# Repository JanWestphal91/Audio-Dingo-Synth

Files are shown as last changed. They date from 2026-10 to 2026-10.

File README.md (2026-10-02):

<h1 align="center">AudioDingo</h1>

<p align="center">
  A pocket-sized, battery-powered synthesizer built on the Arduino UNO R4 Minima and the Mozzi audio library.
</p>

<p align="center">
  
  
  
</p>

<p align="center">
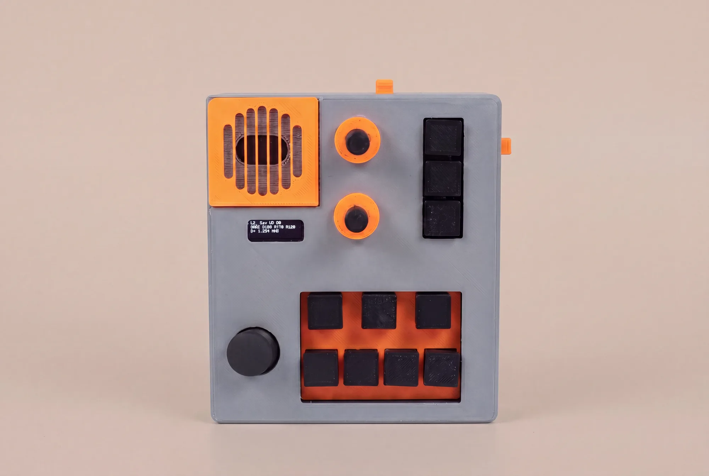
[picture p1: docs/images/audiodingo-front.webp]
AudioDingo front view
  
</p>

AudioDingo is a standalone mini synth with seven note keys, three function buttons, two rotary encoders, a joystick and a small OLED display. It has a built-in speaker for playing on its own and a headphone/line jack for connecting to a larger synth setup. Everything sits in a custom 3D-printed enclosure designed in Fusion 360.

The full design process is documented on my blog: **[Development process of a DIY synthesizer](https://janwestphal.dev/blog/hello-blog/)**

## Demo

<p align="center">
  <a href="https://www.youtube.com/watch?v=iitkykF2S_k">
    AudioDingo demo video on YouTube
  </a>
  <br>
  <em>▶ Watch the demo on YouTube</em>
</p>

## Features

- **6 waveforms:** saw, pulse, triangle, sine, 2-operator FM and noise
- **Chord mode:** each key plays three voices (major, minor, sus4, octaves)
- **5 presets:** lead, bass, FM bell, sub and a sine kick drum
- **"Happy Accident" button:** generates a random patch
- **Resonant low-pass filter** with its own envelope
- **ADSR envelope** you can edit live with an encoder
- **Pitch envelope, LFO, bit crusher and noise layer**, defined per preset
- **Joystick performance controls:** vibrato, wah filter, bit crush and glide
- **128×32 OLED** status screen, plus an animated visualizer mode
- **Portable:** runs on a battery, with a built-in speaker and a headphone/line output

## Design process

The project went from a list of requirements through a simulation, breadboard prototypes and two enclosure iterations to the finished device.

1. **Requirements.** Seven note keys, because a scale has seven notes. Three function buttons and two encoders to shape the sound. A display for feedback. A speaker for standalone use, a jack for the rest of the setup, and a battery for portability.
2. **Simulation.** I tested a first version of the circuit on [Wokwi](https://wokwi.com/).
3. **Breadboard prototype.** I researched which components work together, then built and tested them on a breadboard.
4. **Enclosure v1.** I designed a case in Fusion 360 and printed only the main body, to check the layout with all parts installed.
5. **Iteration.** I soldered the electronics, moved the sound engine to Mozzi and redesigned the case to be wider and deeper, with revised button, cutout and connector dimensions. The second print fit.

<table>
  <tr>
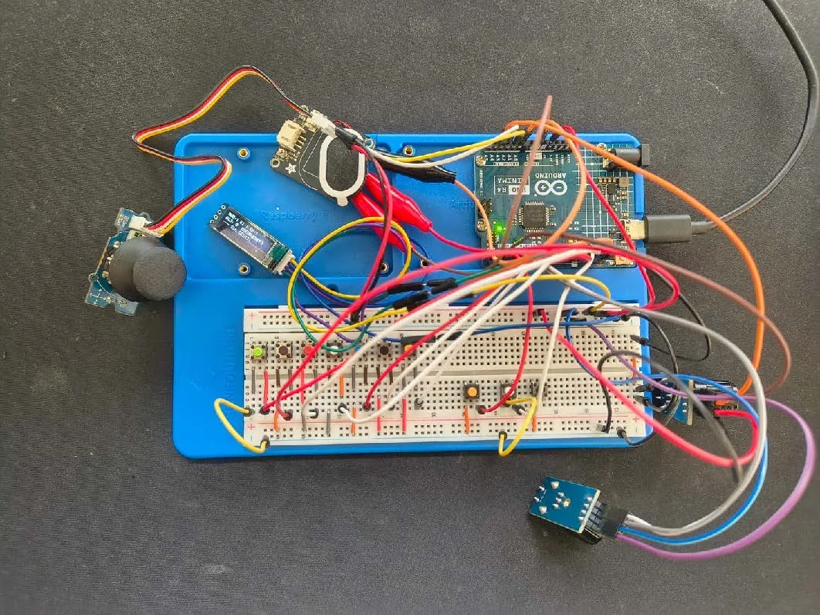
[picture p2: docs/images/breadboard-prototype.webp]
Breadboard prototype
    <td align="center" width="33%"><br><sub>Breadboard prototype</sub></td>
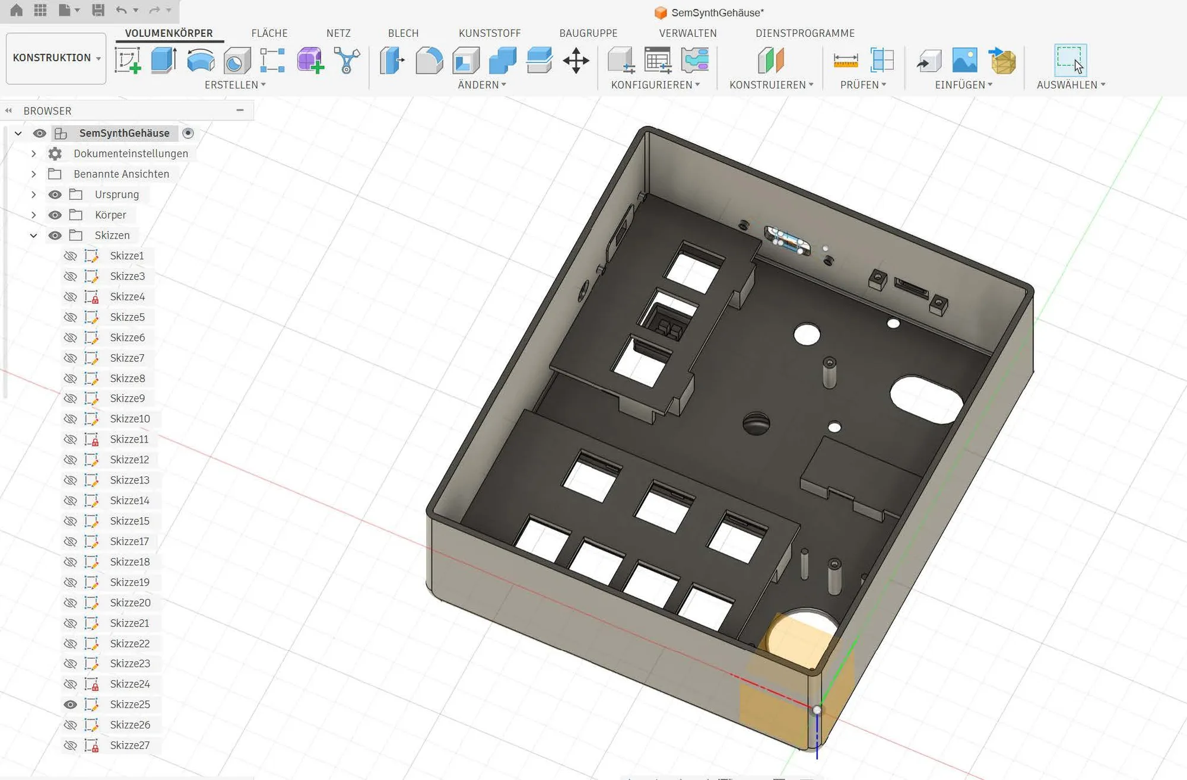
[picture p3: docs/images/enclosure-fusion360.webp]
Enclosure design in Fusion 360
    <td align="center" width="33%"><br><sub>Enclosure design in Fusion 360</sub></td>
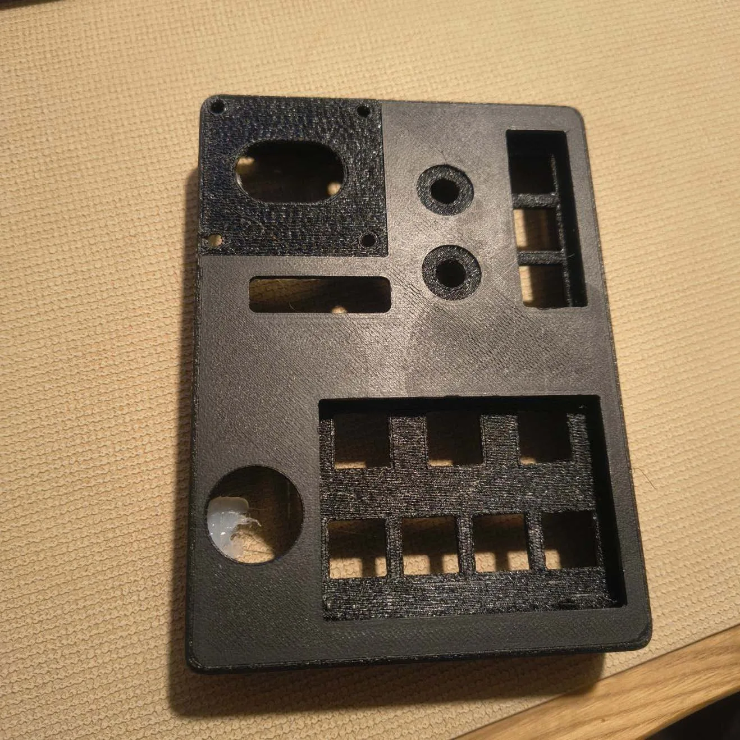
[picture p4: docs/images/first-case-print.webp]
First printed case
    <td align="center" width="33%"><br><sub>First test print of the case</sub></td>
  </tr>
</table>

## Hardware

<p align="center">
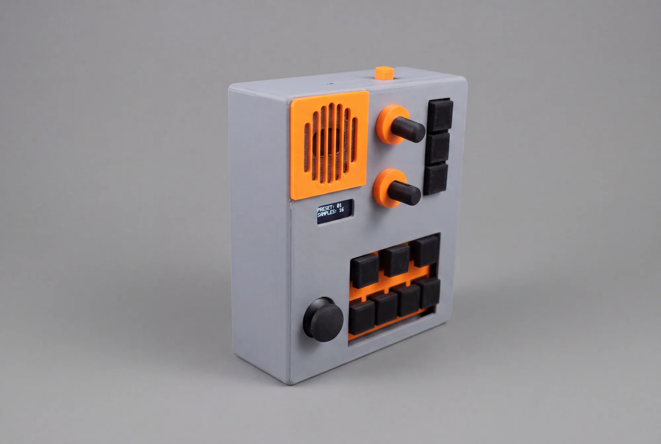
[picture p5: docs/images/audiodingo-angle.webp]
AudioDingo angled view
  
</p>

| Part | Notes |
|---|---|
| Arduino UNO R4 Minima | Outputs audio through its on-board 12-bit DAC on pin A0 |
| 7 push buttons | note keys |
| 3 push buttons | MODE, WAVE, CHORD |
| 2 rotary encoders | quadrature encoders with detents |
| Analog thumb joystick | 2 axes (X/Y) |
| SSD1306 OLED, 128×32, I²C | address `0x3C` |
| Small class-D amplifier + speaker | fed from A0 |
| Headphone / line jack | connects to other synths |
| Battery pack | for portable use |
| 3D-printed enclosure | see [`hardware/enclosure`](hardware/enclosure) |

All buttons connect between the pin and **GND**. The firmware enables the internal pull-up resistors, so you don't need external resistors.

### Pinout

| Pin | Function |
|---|---|
| D12, D11, D10, D9, D8, D7, D6 | Note keys C4 D4 E4 F4 G4 A4 B4 (low to high) |
| D3 | MODE button |
| A4 | WAVE button |
| A5 | CHORD button |
| D4, D5 | Encoder 1 (A, B) |
| D2, A3 | Encoder 2 (A, B) |
| A1, A2 | Joystick X, Y |
| A0 | Audio out (DAC) → amplifier |
| SDA, SCL | OLED display |

You can change every pin in [`firmware/AudioDingo/config.h`](firmware/AudioDingo/config.h).

### Hardware notes

- **Audio output:** On the UNO R4, Mozzi always plays audio through the internal DAC on **A0**. You can't move it to another pin. The firmware also defines A0 as `AMP_ENABLE_PIN`, but once Mozzi is running, the DAC controls the pin.
- **I²C pins:** On the UNO R4 Minima, **A4/A5 are the same pins as SDA/SCL**. In this build, the WAVE and CHORD buttons share these lines with the display. If you build your own, move these two buttons to free pins, e.g. D13 or D0/D1.

## Controls

| Control | Action |
|---|---|
| Note keys | Play a note (or a chord in chord mode) |
| Encoder 1 | Change the selected envelope value (A / D / S / R) |
| Encoder 1 + hold MODE | Select which envelope value to edit |
| Encoder 2 | Volume (1–15) |
| Encoder 2 + hold MODE | Select preset |
| Encoder 2 + hold CHORD | Octave shift −3…+3 (in chord mode) |
| MODE (tap) | Chord mode on/off |
| CHORD (tap) | Next chord type (chord mode) / random patch (otherwise) |
| WAVE (tap) | Next waveform |
| WAVE (hold 0.4 s) | Toggle visualizer screen |
| Joystick ↑ | Vibrato |
| Joystick ↓ | Close filter (wah) |
| Joystick → | Bit crush |
| Joystick ← | Glide / portamento |

### Display

```
Ld  Saw V8 O0          preset, waveform, volume, octave
[A5] D180 S170 R120    envelope; the value being edited is in [brackets]
Dt 1.004 RND           detune, "Crsh" when bit crush is on, chord type (RND = random-patch mode)
```

## How the sound engine works

Every note runs through this chain:

```
 oscillators ──► + noise ──► low-pass filter ──► × envelope ──► × volume ──► bit crush ──► DAC
 (1 or 3 voices)              ▲                    ▲
                              │                    │
             cutoff + filter envelope        amplitude ADSR
             + LFO + joystick
```

- **Oscillators:** Each voice has two oscillators. For saw, pulse and triangle, the second one is slightly detuned and the output is the difference of the two. As the oscillators drift in and out of phase, the waveform keeps changing. For FM, the second oscillator modulates the phase of the first, which produces bell-like and metallic sounds.
- **Control rate and audio rate:** Mozzi calls `updateControl()` 128 times per second to handle inputs, envelopes, pitch and the display. It calls `updateAudio()` 32,768 times per second, and each call computes one sample. The code comments explain why slow work belongs in the first function and only fast math in the second.
- **Click-free display:** An I²C transfer to the OLED briefly pauses audio generation. To avoid clicks, the status screen only redraws when a displayed value has changed.

## Building the firmware

1. Install the **Arduino IDE** (2.x) or `arduino-cli`.
2. Install the board package **Arduino UNO R4 Boards** (`arduino:renesas_uno`).
3. Install these libraries with the Library Manager. The versions listed are the ones I tested:

   | Library | Version |
   |---|---|
   | Mozzi | 2.0.4 |
   | Adafruit SSD1306 | 2.5.17 |
   | Adafruit GFX Library | 1.12.6 |
   | Adafruit BusIO | 1.17.4 (dependency) |
   | FixMath | 1.0.9 (Mozzi dependency) |

4. Open `firmware/AudioDingo/AudioDingo.ino`, select **Arduino UNO R4 Minima** and upload.

With `arduino-cli`:

```bash
arduino-cli compile --fqbn arduino:renesas_uno:minima firmware/AudioDingo
arduino-cli upload  --fqbn arduino:renesas_uno:minima -p <PORT> firmware/AudioDingo
```

## Customizing

| What | Where |
|---|---|
| Pins | `firmware/AudioDingo/config.h` |
| Scale of the note keys | `NOTE_MIDI_NUMBERS` in `config.h` |
| Sounds | `PRESETS[]` and `PRESET_NAMES[]` in `presets.h` (each field is documented in the `Preset` struct) |
| Chords | `CHORD_INTERVALS` in `presets.h` |

## Repository structure

```
├── firmware/AudioDingo/
│   ├── AudioDingo.ino   main program: sound engine, inputs, display, Mozzi callbacks
│   ├── config.h         pins and hardware constants
│   ├── presets.h        waveforms, presets and chord definitions
│   └── encoder.h        debounced rotary encoder decoder
├── hardware/enclosure/  3D-printable enclosure files
└── docs/images/         photos for this README
```

## Credits

- [Mozzi](https://github.com/sensorium/Mozzi) by Tim Barrass and contributors (LGPL-2.1)
- [Adafruit SSD1306](https://github.com/adafruit/Adafruit_SSD1306) and [Adafruit GFX](https://github.com/adafruit/Adafruit-GFX-Library) (BSD)

These libraries are not part of this repository. You install them separately, and their own licenses apply.

## License

[MIT](LICENSE) © 2026 Jan Westphal: firmware, enclosure files and documentation.

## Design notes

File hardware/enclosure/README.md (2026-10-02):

# Enclosure

3D-printable enclosure for AudioDingo, designed in Fusion 360.

<p align="center">
  Enclosure in Fusion 360
</p>

The case is printed in several colors: a grey main body, orange accents and black caps.

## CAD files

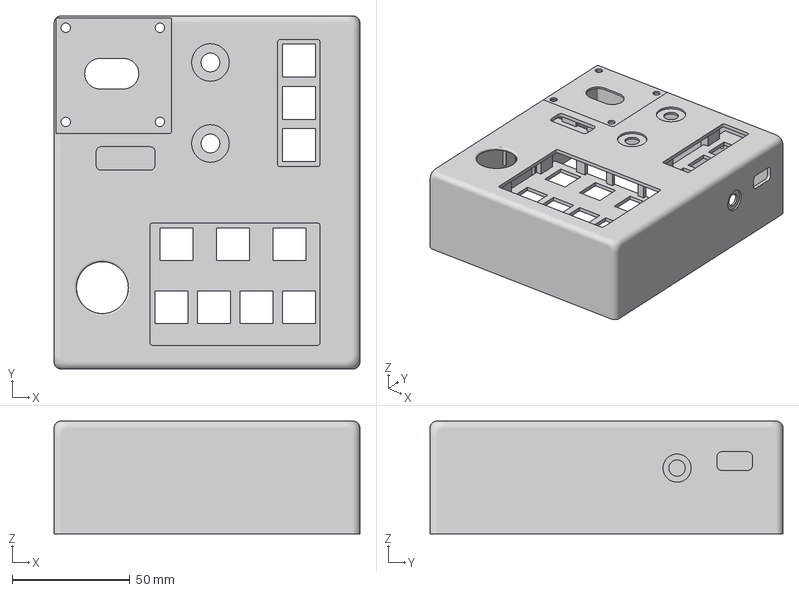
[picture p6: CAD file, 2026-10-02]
hardware/enclosure/DingoCase.3mf
130.0 x 150.0 x 48.0 mm

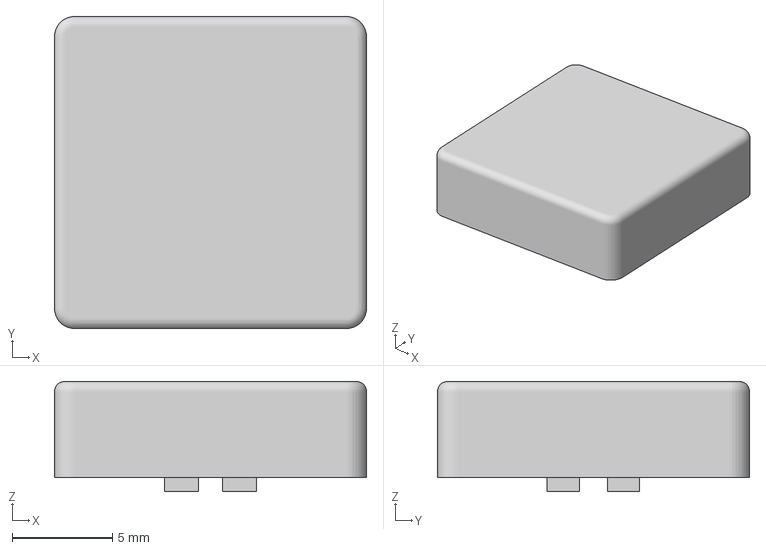
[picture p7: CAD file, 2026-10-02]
hardware/enclosure/Button_small.3mf
15.6 x 15.6 x 5.50 mm

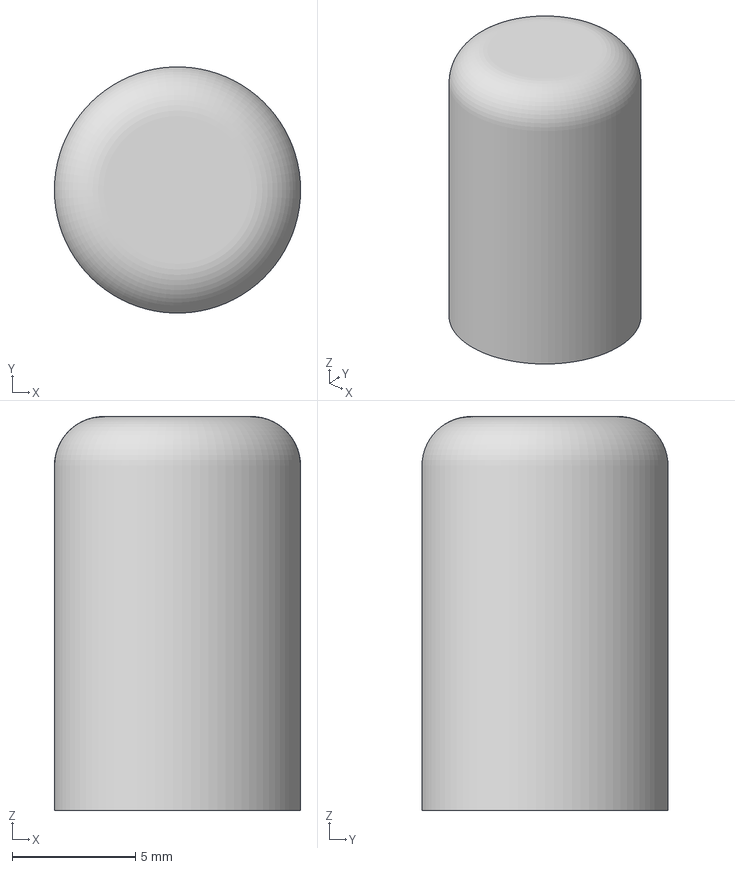
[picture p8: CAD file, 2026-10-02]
hardware/enclosure/Poti_cap.3mf
10.00 x 9.99 x 16.0 mm

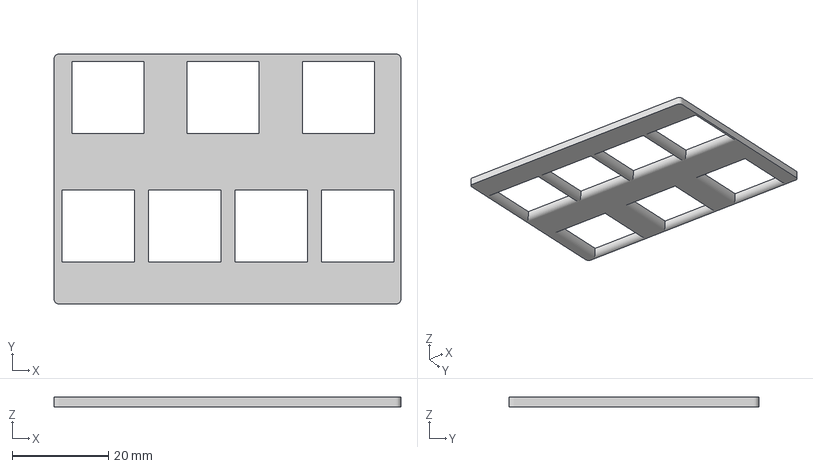
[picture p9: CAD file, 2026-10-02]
hardware/enclosure/Button_Shield.3mf
72.2 x 52.0 x 2.00 mm

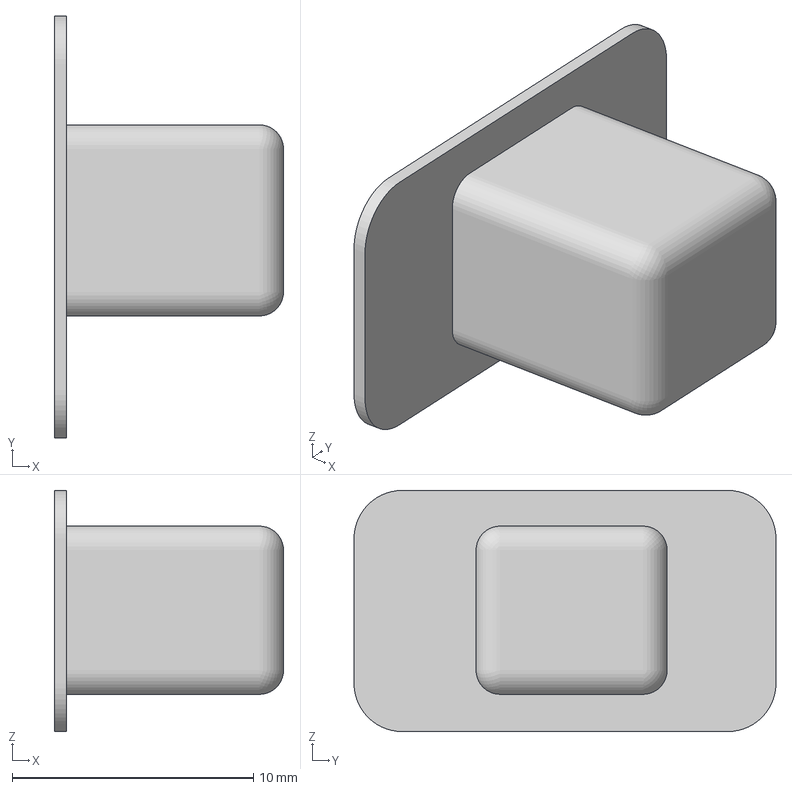
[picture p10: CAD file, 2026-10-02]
hardware/enclosure/Switch_cap.3mf
9.50 x 17.5 x 10.0 mm

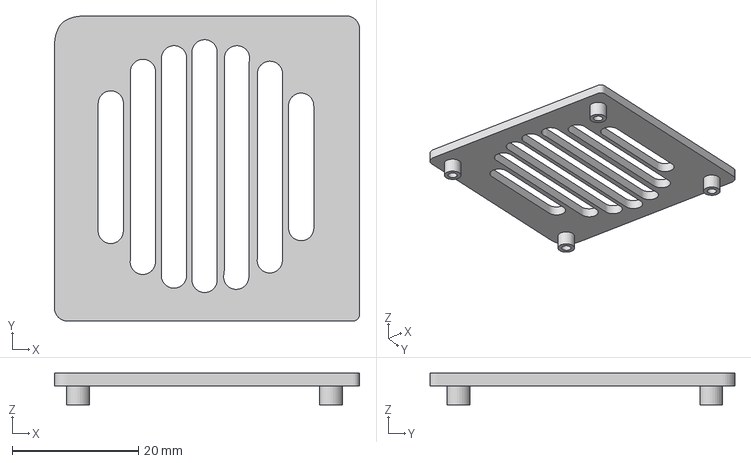
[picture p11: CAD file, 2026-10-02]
hardware/enclosure/speaker_shield.3mf
48.2 x 48.2 x 5.00 mm

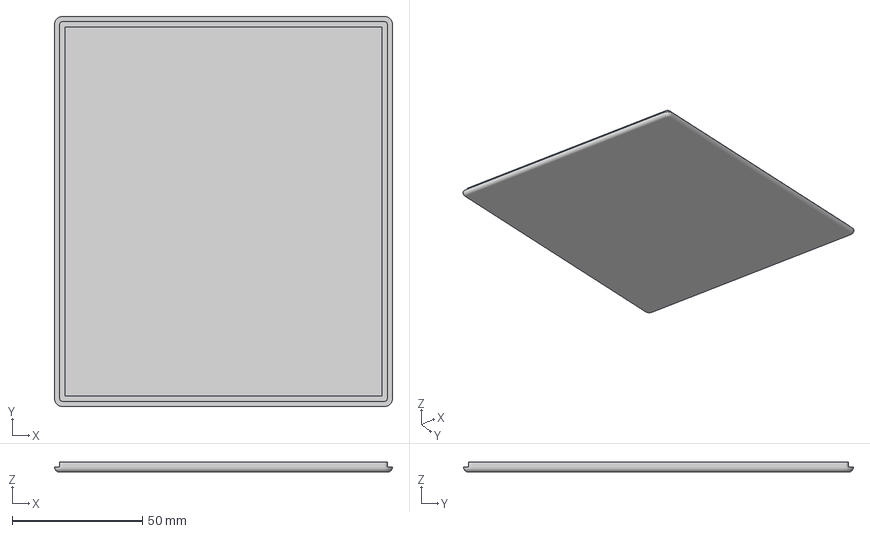
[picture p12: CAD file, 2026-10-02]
hardware/enclosure/Dingo_case2.3mf
130.0 x 150.0 x 4.00 mm

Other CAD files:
hardware/enclosure/poty_ring.3mf

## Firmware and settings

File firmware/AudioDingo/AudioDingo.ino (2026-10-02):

// =============================================================================
//  AudioDingo — a pocket synthesizer for the Arduino UNO R4 Minima
// =============================================================================
//
//  Copyright (c) 2026 Jan Westphal — MIT License (see LICENSE)
//  Project write-up: https://janwestphal.dev/blog/hello-blog/
//
//  A small, battery-powered, 3-voice synthesizer built on the Mozzi audio
//  library. Each preset defines its own waveform, FM, noise, pitch envelope,
//  bit crush and LFO, so the few controls can produce very different sounds —
//  from leads and basses to bells and drum hits.
//
//  ---------------------------------------------------------------------------
//  Controls
//  ---------------------------------------------------------------------------
//   7 note keys          play a note (or a 3-note chord in chord mode)
//
//   Encoder 1            change the selected envelope value (A, D, S or R)
//     + hold MODE        select which envelope value to edit
//
//   Encoder 2            master volume (1..15)
//     + hold MODE        select preset
//     + hold CHORD       octave shift (only in chord mode)
//
//   MODE   (tap)         chord mode on/off
//   CHORD  (tap)         chord mode: next chord type / otherwise: random patch
//   WAVE   (tap)         next waveform
//   WAVE   (hold 0.4 s)  toggle the animated "visualizer" screen
//
//   Joystick up          vibrato
//   Joystick down        close the filter (wah)
//   Joystick right       bit crush
//   Joystick left        glide / portamento between notes
//
//  ---------------------------------------------------------------------------
//  How Mozzi structures the program
//  ---------------------------------------------------------------------------
//  Mozzi splits the work into two callbacks with different speeds:
//
//   updateControl()  runs MOZZI_CONTROL_RATE times per second (here 128 Hz).
//                    Reads buttons, encoders, joystick; updates envelopes,
//                    pitch, filter and the display. Can be relatively slow.
//
//   updateAudio()    runs MOZZI_AUDIO_RATE times per second (32768 Hz on the
//                    R4). Computes ONE audio sample. Must be very fast — no
//                    analogRead(), no display, no floating-point heavy work.
//
//  loop() only calls audioHook(), which keeps Mozzi's audio buffer filled and
//  calls the two functions above when needed. Never use delay() in a Mozzi sketch.
// =============================================================================

// Must be defined BEFORE including Mozzi.h.
#define MOZZI_CONTROL_RATE 128

#include <Mozzi.h>
#include <Phasor.h>
#include <ADSR.h>
#include <LowPassFilter.h>
#include <mozzi_midi.h>

#include <Wire.h>
#include <Adafruit_GFX.h>
#include <Adafruit_SSD1306.h>

#include "config.h"
#include "presets.h"
#include "encoder.h"

// =============================================================================
//  Global objects
// =============================================================================

Adafruit_SSD1306 display(SCREEN_WIDTH, SCREEN_HEIGHT, &Wire, OLED_RESET_PIN);

// Three voices with two oscillators each.
// A Phasor is a simple counter that wraps around once per period. Its 32-bit
// output is the "phase" (position within one waveform cycle), which the wave
// shaper functions below turn into an actual waveform.
//   osc?a = main oscillator (carrier)
//   osc?b = detuned partner OR FM modulator, depending on the waveform
// Voice 1 always plays; voices 2 and 3 are only used in chord mode.
Phasor<MOZZI_AUDIO_RATE> osc1a, osc1b;
Phasor<MOZZI_AUDIO_RATE> osc2a, osc2b;
Phasor<MOZZI_AUDIO_RATE> osc3a, osc3b;

// Two envelopes: one shapes the volume of each note, the other opens and
// closes the filter over the course of a note.
ADSR<MOZZI_CONTROL_RATE, MOZZI_AUDIO_RATE> ampEnvelope;
ADSR<MOZZI_CONTROL_RATE, MOZZI_AUDIO_RATE> filterEnvelope;

// Resonant low-pass filter applied to the mixed voices.
LowPassFilter lowPass;

// Rotary encoders. The pins are passed in swapped order (B, A) on purpose:
// this sets which direction counts as "clockwise" for this particular wiring.
RotaryEncoder encoder1 = {ENC1_PIN_B, ENC1_PIN_A, ENC_REST, 0, 0};
RotaryEncoder encoder2 = {ENC2_PIN_B, ENC2_PIN_A, ENC_REST, 0, 0};

// 256-entry sine lookup table (-127..127), filled in setup().
// Looking up a value is much faster than calling sin() at audio rate.
int8_t sineTable[256];

// =============================================================================
//  Sound parameters (set by presets, partly editable live)
// =============================================================================

// Amplitude envelope: {attack ms, decay ms, sustain level 0..255, release ms}
uint16_t       adsrValues[4] = {5, 150, 180, 80};
const uint16_t ADSR_MIN[4]   = {   1,   20,   0,   20};
const uint16_t ADSR_MAX[4]   = {2000, 2000, 255, 2000};
const int      ADSR_STEP[4]  = {   2,   10,   4,   10};  // change per encoder click
int            adsrEditIndex = 0;                         // which value encoder 1 edits

// Filter
uint8_t filterCutoff    = 220;
uint8_t filterResonance = 30;
uint8_t filterEnvDepth  = 180;

// Oscillators (see presets.h for a description of each parameter)
uint8_t  waveform     = WAVE_SAW;
float    detune       = 1.003f;
float    fmRatio      = 1.0f;
uint8_t  fmDepth      = 0;
uint8_t  noiseMix     = 0;
int8_t   pitchDrop    = 0;
uint16_t pitchDropMs  = 0;
uint8_t  crushAmount  = 1;
uint8_t  lfoRate      = 0;
uint8_t  lfoDepth     = 0;
uint8_t  lfoDest      = LFO_TO_PITCH;
int8_t   presetOctave = 0;

// =============================================================================
//  Performance state
// =============================================================================

int  currentPreset = 0;
int  volume        = 8;      // 1..15, index into VOLUME_CURVE
int  octaveShift   = 0;      // -3..+3, set with CHORD + encoder 2
bool chordMode     = false;
int  chordType     = 0;      // index into CHORD_INTERVALS

// Our ears perceive loudness logarithmically, so equal encoder steps should
// multiply the level, not add to it. Each 3 steps roughly double the level
// (about +6 dB); 256 = full scale.
const uint16_t VOLUME_CURVE[16] = {8, 10, 13, 16, 20, 25, 32, 40, 51, 64, 81, 102, 128, 161, 203, 256};

// Currently sounding note
int           activeNote    = -1;      // index into NOTE_MIDI_NUMBERS, -1 = silent
bool          activeIsChord = false;
unsigned long noteStartMs   = 0;       // for the pitch envelope
int           lastNoteKey   = -1;      // key held during the previous control tick

// Joystick-controlled modulation (updated in readJoystick())
int   joyFilterOffset = 0;      // down:  negative filter offset (wah)
float joyVibratoDepth = 0.0f;   // up:    vibrato depth in semitones
int   joyCrush        = 0;      // right: extra bit crush
float glideSpeed      = 1.0f;   // left:  portamento (1.0 = instant, smaller = slower)
float glidePitch      = 60.0f;  // current (gliding) pitch as a fractional MIDI note

// LFOs — phases run from 0 to 256 (one sine-table cycle), values are -127..127
float vibratoPhase = 0.0f;      // fixed 5.5 Hz LFO used by the joystick vibrato
int   vibratoValue = 0;
float lfoPhase     = 0.0f;      // preset LFO
int   lfoValue     = 0;

// Button edge detection (buttons read LOW while pressed)
bool lastModeState  = HIGH;
bool lastChordState = HIGH;
bool lastWaveState  = HIGH;
bool modeUsedAsShift = false;   // MODE was held while turning an encoder -> don't toggle chord mode
bool waveLongPressed = false;
unsigned long wavePressStartMs = 0;

// Display
bool          animationMode       = false;  // true = show visualizer instead of status
unsigned long randomPatchBannerEndMs = 0;   // show "Happy Accident" message until this time
int           displayTickCounter  = 0;

// =============================================================================
//  Fast random numbers for the noise generator
// =============================================================================
// xorshift32: a tiny pseudo-random generator — just three shifts and XORs —
// fast enough to run once or twice per audio sample.
uint32_t rngState = 0x1234abcdUL;

static inline uint8_t fastRandom8() {
  rngState ^= rngState << 13;
  rngState ^= rngState >> 17;
  rngState ^= rngState << 5;
  return (uint8_t)rngState;
}

// =============================================================================
//  Sound engine: applying parameters
// =============================================================================

// Push the current ADSR values into both envelopes.
// Sustain time is set to 60 s, i.e. "as long as the key is held".
void applyEnvelopes() {
  ampEnvelope.setADLevels(255, adsrValues[2]);
  ampEnvelope.setTimes(adsrValues[0], adsrValues[1], 60000, adsrValues[3]);

  // The filter envelope uses the same timing but a fixed sustain level.
  filterEnvelope.setADLevels(255, 80);
  filterEnvelope.setTimes(adsrValues[0], adsrValues[1], 60000, adsrValues[3]);
}

// Copy a preset from the table into the live parameters.
void loadPreset(int index) {
  const Preset &p = PRESETS[index];

  adsrValues[0] = p.attack;
  adsrValues[1] = p.decay;
  adsrValues[2] = p.sustain;
  adsrValues[3] = p.release;

  filterCutoff    = p.cutoff;
  filterResonance = p.resonance;
  filterEnvDepth  = p.filterEnvDepth;

  presetOctave = p.octave;
  waveform     = p.wave;
  fmRatio      = p.fmRatio;
  fmDepth      = p.fmDepth;
  noiseMix     = p.noiseMix;
  detune       = p.detune;
  pitchDrop    = p.pitchDrop;
  pitchDropMs  = p.pitchTime;
  crushAmount  = p.crush;
  lfoRate      = p.lfoRate;
  lfoDepth     = p.lfoDepth;
  lfoDest      = p.lfoDest;

  applyEnvelopes();
}

// "Happy accident" button: roll random values for (almost) every parameter.
// The ranges are chosen so the result is usually playable.
void randomizePatch() {
  adsrValues[0] = random(2, 300);
  adsrValues[1] = random(40, 400);
  adsrValues[2] = random(40, 255);
  adsrValues[3] = random(20, 500);

  filterCutoff    = random(80, 255);
  filterResonance = random(5, 120);
  filterEnvDepth  = random(40, 220);

  detune       = 1.000f + random(0, 15) * 0.001f;
  presetOctave = random(-1, 2);
  waveform     = random(0, NUM_WAVEFORMS);

  // Integer and simple fractional ratios give harmonic FM tones,
  // odd ones like 3.5 or 7 give bell-like, inharmonic tones.
  const float FM_RATIOS[] = {1.0f, 1.5f, 2.0f, 3.0f, 3.5f, 5.0f, 7.0f};
  fmRatio = FM_RATIOS[random(0, 7)];
  fmDepth = random(20, 120);

  // Noise and pitch drop only in about one out of three patches
  noiseMix    = (random(0, 3) == 0) ? random(20, 120) : 0;
  pitchDrop   = (random(0, 3) == 0) ? random(6, 40) : 0;
  pitchDropMs = random(50, 200);

  crushAmount = random(1, 5);

  // LFO on in about half of the patches
  lfoRate  = (random(0, 2) == 0) ? random(3, 80) : 0;
  lfoDepth = random(8, 50);
  lfoDest  = random(0, 2);

  applyEnvelopes();
  randomPatchBannerEndMs = millis() + 900;
}

// =============================================================================
//  Sound engine: pitch
// =============================================================================

// Recalculate the frequency of every active oscillator.
// Called on every control tick, because glide, pitch envelope and vibrato all
// change the pitch continuously while a note is held.
void updatePitch() {
  if (activeNote < 0) return;

  // Glide: move a fraction of the remaining distance towards the target note on
  // every tick. glideSpeed 1.0 jumps immediately; small values slide slowly.
  float targetPitch = NOTE_MIDI_NUMBERS[activeNote] + (octaveShift + presetOctave) * 12;
  glidePitch += glideSpeed * (targetPitch - glidePitch);

  // Pitch envelope: start `pitchDrop` semitones higher, fall linearly to 0.
  float drop = 0.0f;
  if (pitchDrop != 0 && pitchDropMs > 0) {
    unsigned long elapsed = millis() - noteStartMs;
    if (elapsed < pitchDropMs) drop = pitchDrop * (1.0f - (float)elapsed / pitchDropMs);
  }

  // Preset LFO as vibrato (in semitones)
  float lfoVibrato = (lfoDest == LFO_TO_PITCH) ? (lfoValue / 127.0f) * lfoDepth * 0.05f : 0.0f;

  // Joystick vibrato (in semitones)
  float joyVibrato = (vibratoValue / 127.0f) * joyVibratoDepth;

  // Oscillator b runs at a multiple of oscillator a:
  //   FM:     the modulator ratio (e.g. 3.5 for bells)
  //   others: the detune factor (e.g. 1.004 -> slightly sharp -> beating/chorus)
  float partnerRatio = (waveform == WAVE_FM) ? fmRatio : detune;

  // Everything above is in (fractional) MIDI notes; mtof() converts to Hz.
  float pitch = glidePitch + drop + lfoVibrato + joyVibrato;

  float freq1 = mtof(pitch);
  osc1a.setFreq(freq1);
  osc1b.setFreq(freq1 * partnerRatio);

  if (activeIsChord) {
    float freq2 = mtof(pitch + CHORD_INTERVALS[chordType][0]);
    float freq3 = mtof(pitch + CHORD_INTERVALS[chordType][1]);
    osc2a.setFreq(freq2);
    osc2b.setFreq(freq2 * partnerRatio);
    osc3a.setFreq(freq3);
    osc3b.setFreq(freq3 * partnerRatio);
  }
}

// =============================================================================
//  Sound engine: note on / note off
// =============================================================================

void noteOn(int noteIndex, bool asChord) {
  activeNote    = noteIndex;
  activeIsChord = asChord;
  noteStartMs   = millis();
  ampEnvelope.noteOn(true);      // true = restart the envelope from zero
  filterEnvelope.noteOn(true);
  digitalWrite(AMP_ENABLE_PIN, HIGH);
  updatePitch();
}

// Starts the release phase; the note fades out according to the envelope.
void noteOff() {
  ampEnvelope.noteOff();
  filterEnvelope.noteOff();
  activeNote    = -1;
  activeIsChord = false;
}

// Monophonic key handling: only (re)trigger when the pressed key changes.
// Retriggering on every tick would restart the envelope constantly.
void handleNoteKeys(int pressedKey) {
  if (pressedKey == lastNoteKey) return;
  if (pressedKey >= 0) noteOn(pressedKey, chordMode);
  else                 noteOff();
  lastNoteKey = pressedKey;
}

// Returns the index of the lowest pressed note key, or -1 if none is pressed.
int readNoteKeys() {
  for (int i = 0; i < NUM_NOTE_BUTTONS; i++) {
    if (digitalRead(NOTE_BUTTON_PINS[i]) == LOW) return i;
  }
  return -1;
}

// =============================================================================
//  LFOs
// =============================================================================

// Advance both LFOs by one control tick.
// Phase increment per tick = frequency / tick rate * table length.
void updateLfos() {
  // Fixed 5.5 Hz LFO for the joystick vibrato (always running)
  vibratoPhase += 5.5f / MOZZI_CONTROL_RATE * 256.0f;
  while (vibratoPhase >= 256.0f) vibratoPhase -= 256.0f;
  vibratoValue = sineTable[(uint8_t)vibratoPhase];

  // Preset LFO (lfoRate is in 0.1 Hz steps)
  if (lfoRate == 0) {
    lfoValue = 0;
    return;
  }
  lfoPhase += (float)lfoRate * 0.1f / MOZZI_CONTROL_RATE * 256.0f;
  while (lfoPhase >= 256.0f) lfoPhase -= 256.0f;
  lfoValue = sineTable[(uint8_t)lfoPhase];
}

// =============================================================================
//  Inputs
// =============================================================================

// Encoder 1: edit the envelope. With MODE held, choose which value to edit.
void handleEncoder1() {
  int steps = encoderTakeSteps(encoder1);
  if (steps == 0) return;
  int dir = (steps > 0) ? 1 : -1;
  int count = abs(steps);

  if (digitalRead(MODE_BUTTON_PIN) == LOW) {
    // Wrap around 0..3 (the "+ 4) % 4" keeps the result positive)
    adsrEditIndex   = ((adsrEditIndex + dir * count) % 4 + 4) % 4;
    modeUsedAsShift = true;
  } else {
    adsrValues[adsrEditIndex] = (uint16_t)constrain(
      (int)adsrValues[adsrEditIndex] + dir * count * ADSR_STEP[adsrEditIndex],
      ADSR_MIN[adsrEditIndex], ADSR_MAX[adsrEditIndex]);
    applyEnvelopes();
  }
  animationMode = false;
}

// Encoder 2: volume. With MODE held: preset. With CHORD held in chord mode: octave.
void handleEncoder2() {
  int steps = encoderTakeSteps(encoder2);
  if (steps == 0) return;
  int dir = (steps > 0) ? 1 : -1;
  int count = abs(steps);

  if (digitalRead(CHORD_BUTTON_PIN) == LOW && chordMode) {
    octaveShift = constrain(octaveShift + dir * count, -3, 3);
  } else if (digitalRead(MODE_BUTTON_PIN) == LOW) {
    currentPreset   = ((currentPreset + dir * count) % NUM_PRESETS + NUM_PRESETS) % NUM_PRESETS;
    loadPreset(currentPreset);
    modeUsedAsShift = true;
  } else {
    volume = constrain(volume + dir * count, 1, 15);
  }
  animationMode = false;
}

// CHORD button, acts on press:
//   animation screen visible -> leave it
//   chord mode               -> next chord type
//   otherwise                -> random patch
void handleChordButton() {
  bool state = digitalRead(CHORD_BUTTON_PIN);

  if (lastChordState == HIGH && state == LOW) {
    if      (animationMode) animationMode = false;
    else if (chordMode)     chordType = (chordType + 1) % NUM_CHORD_TYPES;
    else                    randomizePatch();
  }
  lastChordState = state;
}

// MODE button, acts on release, so it can double as a "shift" key:
// if an encoder was turned while it was held, releasing it does nothing.
void handleModeButton() {
  bool state = digitalRead(MODE_BUTTON_PIN);

  if (lastModeState == HIGH && state == LOW) {        // pressed
    modeUsedAsShift = false;
  }
  if (lastModeState == LOW && state == HIGH) {        // released
    if (!modeUsedAsShift) {
      if (animationMode) animationMode = false;
      else               chordMode = !chordMode;
    }
    modeUsedAsShift = false;
  }
  lastModeState = state;
}

// WAVE button: short press = next waveform, long press (400 ms) = animation.
// The long press fires while still holding; the short press fires on release.
void handleWaveButton() {
  bool state = digitalRead(WAVE_BUTTON_PIN);

  if (lastWaveState == HIGH && state == LOW) {        // pressed
    wavePressStartMs = millis();
    waveLongPressed  = false;
  }

  if (state == LOW && !waveLongPressed && millis() - wavePressStartMs >= 400) {
    waveLongPressed = true;
    animationMode   = !animationMode;
  }

  if (lastWaveState == LOW && state == HIGH) {        // released
    if (!waveLongPressed) {
      if (animationMode) {
        animationMode = false;
      } else {
        waveform = (waveform + 1) % NUM_WAVEFORMS;
        // Retrigger a held note so the new waveform is heard right away
        if (activeNote >= 0) noteOn(activeNote, activeIsChord);
      }
    }
    waveLongPressed = false;
  }
  lastWaveState = state;
}

// Joystick: each of the four directions controls a separate effect.
void readJoystick() {
  int x = analogRead(JOY_X_PIN) - JOY_CENTER_X;
  int y = analogRead(JOY_Y_PIN) - JOY_CENTER_Y;
  if (abs(x) < JOY_DEAD_ZONE) x = 0;
  if (abs(y) < JOY_DEAD_ZONE) y = 0;

  // Deflection per direction, normalized to 0..1.
  // (If your joystick is mounted differently, swap the signs here.)
  float down  = (y > 0) ? constrain( y / (float)JOY_FULL_DEFLECTION, 0.0f, 1.0f) : 0.0f;
  float up    = (y < 0) ? constrain(-y / (float)JOY_FULL_DEFLECTION, 0.0f, 1.0f) : 0.0f;
  float left  = (x < 0) ? constrain(-x / (float)JOY_FULL_DEFLECTION, 0.0f, 1.0f) : 0.0f;
  float right = (x > 0) ? constrain( x / (float)JOY_FULL_DEFLECTION, 0.0f, 1.0f) : 0.0f;

  joyFilterOffset = -(int)(down * 200.0f);   // down:  close filter by up to 200
  joyVibratoDepth = up * 0.6f;               // up:    vibrato up to +/-0.6 semitones
  joyCrush        = (int)(right * 6.0f);     // right: add 0..6 crush steps
  glideSpeed      = 1.0f - left * 0.97f;     // left:  glide from instant (1.0) to slow (0.03)
}

// =============================================================================
//  Display
// =============================================================================

// "Plasma" visualizer: a 32x8 grid of dots whose size follows the sum of four
// moving sine waves. Purely decorative.
void drawAnimation() {
  display.clearDisplay();
  float t = millis() / 700.0f;

  for (int row = 0; row < 8; row++) {
    for (int col = 0; col < 32; col++) {
      float x = col / 8.0f;
      float y = row / 4.0f;
      float v = sin(x + t)
              + sin(y + t * 0.7f)
              + sin((x + y) * 0.5f + t * 1.3f)
              + sin(sqrt(x * x + y * y + 0.001f) + t * 0.9f);
      float level = (v + 4.0f) / 8.0f;       // sum of 4 sines (-4..4) -> 0..1

      int px = col * 4, py = row * 4;
      if      (level > 0.66f) display.fillRect(px, py, 3, 3, SSD1306_WHITE);
      else if (level > 0.33f) display.fillRect(px, py, 2, 2, SSD1306_WHITE);
      else if (level > 0.15f) display.drawPixel(px, py, SSD1306_WHITE);
    }
  }
  display.display();
}
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
void loop() {
  audioHook();        // let Mozzi fill the audio buffer (calls updateControl/updateAudio)

  // Encoders are polled here, as often as possible, rather than only at the
  // 128 Hz control rate — otherwise fast turns would skip steps.
  encoderPoll(encoder1);
  encoderPoll(encoder2);
}

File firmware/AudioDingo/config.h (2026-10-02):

// =============================================================================
//  config.h — Hardware configuration for AudioDingo
// =============================================================================
//
//  Everything that depends on how *your* board is wired lives here.
//  If you build your own version with a different pinout, this should be
//  the only file you need to touch.
//
//  All buttons are wired between the pin and GND and use the internal
//  pull-up resistor, so a pressed button reads LOW.
// =============================================================================
#pragma once

#include <Arduino.h>

// -----------------------------------------------------------------------------
//  Note keys
// -----------------------------------------------------------------------------
// Seven keys, one per note of a C major scale (see NOTE_MIDI_NUMBERS below).
// Order matters: index 0 is the lowest note.
const uint8_t NOTE_BUTTON_PINS[] = {12, 11, 10, 9, 8, 7, 6};
const int     NUM_NOTE_BUTTONS   = 7;

// MIDI note numbers played by the seven keys: C4 D4 E4 F4 G4 A4 B4.
// Change these to play a different scale.
const uint8_t NOTE_MIDI_NUMBERS[] = {60, 62, 64, 65, 67, 69, 71};

// -----------------------------------------------------------------------------
//  Function buttons
// -----------------------------------------------------------------------------
const uint8_t MODE_BUTTON_PIN  = 3;   // chord mode on/off, "shift" for both encoders
const uint8_t WAVE_BUTTON_PIN  = A4;  // cycle waveform / long press: animation screen
const uint8_t CHORD_BUTTON_PIN = A5;  // next chord type / random patch, "shift" for encoder 2

// NOTE: On the UNO R4 Minima, A4 and A5 are also the I2C lines (SDA/SCL) used
// by the OLED display. In this build the two buttons share those lines with
// the display. If you build your own, consider moving them to free pins
// (e.g. D13, or D0/D1 if you don't need the serial pins).

// -----------------------------------------------------------------------------
//  Rotary encoders (quadrature, two signal pins each)
// -----------------------------------------------------------------------------
const uint8_t ENC1_PIN_A = 4;
const uint8_t ENC1_PIN_B = 5;
const uint8_t ENC2_PIN_A = 2;
const uint8_t ENC2_PIN_B = A3;

// -----------------------------------------------------------------------------
//  Analog joystick
// -----------------------------------------------------------------------------
const uint8_t JOY_X_PIN = A1;
const uint8_t JOY_Y_PIN = A2;

const int JOY_CENTER_X        = 512;  // ADC reading at rest (10-bit ADC: 0..1023)
const int JOY_CENTER_Y        = 512;
const int JOY_DEAD_ZONE       = 40;   // ignore small movements around the center
const int JOY_FULL_DEFLECTION = 250;  // distance from center that counts as "100 %"

// -----------------------------------------------------------------------------
//  Audio amplifier
// -----------------------------------------------------------------------------
// Pin driven HIGH when a note starts and LOW when the voice is silent,
// intended for the shutdown (SD) input of a small class-D amplifier.
//
// NOTE: On the UNO R4, Mozzi sends its audio through the on-board DAC,
// which is hard-wired to pin A0. The amplifier's audio input therefore
// connects to A0. See the "Audio output" section in the README.
const uint8_t AMP_ENABLE_PIN = A0;

// -----------------------------------------------------------------------------
//  OLED display (SSD1306, I2C)
// -----------------------------------------------------------------------------
const int     SCREEN_WIDTH   = 128;
const int     SCREEN_HEIGHT  = 32;
const int8_t  OLED_RESET_PIN = -1;    // -1 = display shares the Arduino's reset line
const uint8_t OLED_I2C_ADDR  = 0x3C;
